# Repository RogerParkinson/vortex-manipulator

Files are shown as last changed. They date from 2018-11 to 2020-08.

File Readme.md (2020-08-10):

Vortex Manipulator
=

Mostly inspired by the wrist device worn by Captain Jack Harkness in _Dr Who_ and _Torchwood_, hence the name. However the design wandered somewhat from that initial idea so the look is a bit different. This is the idea I started with:

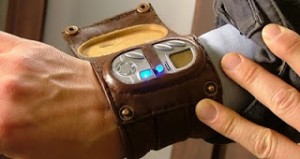
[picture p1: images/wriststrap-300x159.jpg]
VM


Mine is a little different, I needed more space to do what I want, so it is a bit fatter and it doesn't actually manipulate a time vortex (whatever that is). Instead it has the following functions:

 * Touch screen interface
 * Clock with optional beep and LED flash once a second, plus a function to set the time. It doesn't adjust automatically for daylight savings etc, but there is a UI to set the time manually.
 * Compass
 * Graphics demo
 * Dalek detector
 * Picture gallery (displays pictures from the SD card)
 * Heart rate monitor, including display graph and data log to SD card.
 * Sleep (power save) function, wakes up when the power button is pressed.
 * Notifications board. Messages from a Bluetooth device (eg a phone) display here.

Watch the video (https://youtu.be/WImzifKEVy0)

[Lots more details here](https://github.com/RogerParkinson/vortex-manipulator)

Hardware consists of a Teensy 3.2 mounted on a custom board [the Main Board](eagle/MainBoard/Readme.md) which contains circuitry for charging the attached LiPo battery when the USB port is connected, and an LSM303 to provide compass and accelerometer functions.

A second [ILI9341 custom connector board](eagle/ILI9341-Touch-connector/Readme.md) connects to an ILI9341 touch screen. This board has a touch controller and a connector strip that matches the strip on the side of the main board.

There are some configuration settings stored on the SD card (file is hconfig.txt) which consists of the time zone, low pulse and high pulse rates. The pulse rates are used by the HRM to sound alarms if the pulse is outside that range. The time zone is used for the clock (except it isn't actually used now). The other files on the SD card are bmp files used for the picture gallery. These must be 240x320 images. All of these files are in the SDBackup directory.

Perhaps more importantly it is a development _platform_. There is plenty of spare capacity in the Teensy and there is still plenty of room in the assembly to add more stuff. The Main Board has connectors to unused pins on the Teensy as well. An example of adding more stuff is the heart rate monitor. I got hold of a better one which uses an I2C interface and, hardware-wise, it was simple to add the extra connections to the SDA and SCL for it, then a bit more programming and the job was done.

The assembly is a mix of leather and a 3D printed frame.

Parts
-

 * [Teensy 3.2](https://www.pjrc.com/store/teensy32.html) microprocessor board
 * [LSM303](http://nz.element14.com/stmicroelectronics/lsm303dlhc/sensor-3-ch-accel-mag-mod-14lga/dp/2068595) Compass/accelerometer IC *
 * [SD Card Reader](https://www.aliexpress.com/item/Free-Shipping-5PCS-67840-8001-Conn-SD-Card-HDR-9-POS-Solder-RA-SMD-Embossed-T/32651979617.html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,searchweb201602_3_10152_10065_10151_10068_436_10136_10157_10137_10060_10138_10155_10062_10156_10154_10056_10055_10054_10059_100032_100033_100031_10099_10103_10102_10096_10147_10052_10053_10050_10107_10142_10051_10084_10083_10080_10082_10081_10110_10175_10111_10112_10113_10114_10181_10037_10183_10182_10185_10033_10032_10078_10079_10077_10073_10070_10123,searchweb201603_2,ppcSwitch_4&btsid=7b9c1a86-e8c1-4082-b529-14cabbf02189&algo_expid=712bfc6c-3058-4115-9f9d-6d221787d2ec-1&algo_pvid=712bfc6c-3058-4115-9f9d-6d221787d2ec) *
 * [Lipo Battery 3.7v](https://www.aliexpress.com/item/3-7V-1000mah-753050-Lithium-Polymer-LiPo-Rechargeable-Battery-For-Mp3-MP4-MP5-DVD-PAD-mobile/32293277274.html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,searchweb201602_3_10152_10065_10151_10068_436_10136_10157_10137_10060_10138_10155_10062_10156_10154_10056_10055_10054_10059_100032_100033_100031_10099_10103_10102_10096_10147_10052_10053_10050_10107_10142_10051_10084_10083_10080_10082_10081_10110_10175_10111_10112_10113_10114_10181_10037_10183_10182_10185_10032_10078_10079_10077_10073_10070_10123,searchweb201603_2,ppcSwitch_4&btsid=7691371f-396d-424d-b6fc-32f0ece90527&algo_expid=46b76ba9-9c3b-4e16-846a-75c4c1e89c21-4&algo_pvid=46b76ba9-9c3b-4e16-846a-75c4c1e89c21)
 * [2.4" 240x320 SPI Serial TFT Color LCD Display Module+ILI9341 Touch Panel Screen](https://www.aliexpress.com/item/2-8-2-8-Inch-240x320-SPI-Serial-TFT-Color-LCD-Display-Module-Touch-Panel-Screen/32681743271.html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) Make sure you get a *touch* screen, there are screens in the same format/packing that just display with no touch.
 * [XPT2046 Touch Controller](https://www.aliexpress.com/item/Free-shipping-20pcs-lot-XPT2046-2046-TSSOP16-new-original/32639677099.html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) *
 * [MCP73811](https://www.aliexpress.com/item/100-new-origina-MCP73811T-420I-OT-battery-management-chip-73811-MCP73811-Free-shipping-best-match/32713220952.html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,searchweb201602_3_10065_10068_10547_319_317_10548_10696_10084_453_10924_10083_454_10925_10926_10618_10920_10921_10307_10922_537_536_5733313_5733211_10059_10884_5733113_10887_100031_321_5733413_322_10103_5733612_5733513,searchweb201603_2,ppcSwitch_0&algo_expid=36e5927f-8c98-4996-90c5-7ffab6aace2d-0&algo_pvid=36e5927f-8c98-4996-90c5-7ffab6aace2d) battery management chip *
 * [LP298X](http://www.datasheetcafe.com/lp298xs-datasheet-low-dropout-regulator/) voltage regulator *
 * [Speaker 8 ohm](https://www.aliexpress.com/item/Manufacturers-direct-sales-round-8-European-1W-speaker-1w8-European-speakers-8-European-1W-speaker-20mm/32777445698.html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)
 * 2 LEDs (blue and green, or whatever colour you prefer)
 * 32.768Khz Crystal [soldered to the under side of the Teensy](https://www.pjrc.com/teensy/td_libs_Time.html) and a Coin Cell battery (CR2032) and holder.
 * [Switch](https://www.aliexpress.com/item/MINI-micro-Slide-Switch-On-OFF-2-Position-1P2T-SPDT-Miniature-Horizontal-Slide-Switch-SMD-7/32655484942.html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,searchweb201602_3_10152_10065_10151_10068_436_10136_10157_10137_10060_10138_10155_10062_10156_10154_10056_10055_10054_10059_100032_100033_100031_10099_10103_10102_10096_10147_10052_10053_10050_10107_10142_10051_10084_10083_10080_10082_10081_10110_10175_10111_10112_10113_10114_10181_10037_10183_10182_10185_10032_10078_10079_10077_10073_10070_10123,searchweb201603_2,ppcSwitch_4&btsid=4943b00a-2810-4553-922c-abebd41b5fcd&algo_expid=9ef925ce-c813-4853-b9b8-157b1cc2ff52-0&algo_pvid=9ef925ce-c813-4853-b9b8-157b1cc2ff52) *
 * [Button](https://www.aliexpress.com/item/Promotion-Amico-100-Pcs-6x6x4-5mm-Panel-PCB-Momentary-Tactile-Tact-Push-Button-Switch-4-Pin/32563399489.html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)
 * Various caps and resistors (see circuit diagrams for the boards)
 * [Heart Rate Monitor](https://www.aliexpress.com/item/Low-Power-MAX30102-Heart-Rate-Oxygen-Pulse-Breakout-for-Arduino-Replace-MAx30100/32892216359.html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) MAX30102 based breakout board.
 
Those marked with * are all surface mounted (SMD) parts.
 
Making the Icons
-

I developed an interesting technique for generating the icons for this project and I put it in its own [project](https://github.com/RogerParkinson/MakeIcons).

The SD card
-

The project uses an SD Card and you'll find a copy of mine in the SDBackup directory. It includes some bmp files which are images displayed by the gallery app, a configuration file calle hconfig.txt and a log file called datalog.txt.

The configuration file is one line: 12,120,150,
the 12 was once a timezone but I no longer use that. 120 and 150 are heart rate limits. The display turns green when you pass 120 and red when you pass 150. For me green means I'm in a good exercise zone, but your numbers may be different.

You can add your own bmp files. As long as they are 240x320 BMP format they will display in the gallery. When I export mine from Gimp I use these settings:

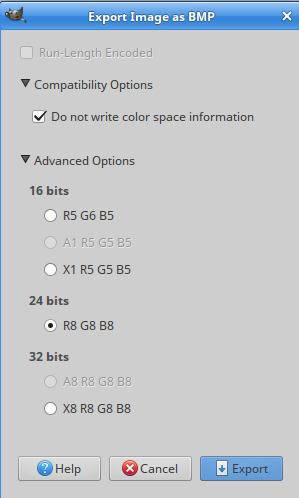
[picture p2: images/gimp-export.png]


Finally the datalog.txt file is a log of heart rates. The first column is a timestamp, then the beats per minute and finally the last interval between beats. It logs this every 10 minutes, the time is set in the setup() method in VortexManipulator.cpp:

```
intervals.create(10*60*1000L,new HRLogAction()); // 10 minutes
```

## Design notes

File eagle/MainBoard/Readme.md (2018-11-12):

Main board for the Vortex Manipulator
==

Main components:

 * Teensy 3.2 board. This holds the processor and the USB connector. It also has an on board clock powered by the small battery.
 * MicroSD. This holds configuration files and images. Heart rate logs go here.
 * LSM303 which provides a compass and an accelerometer.
 * LIPO charger circuit which charges the LIPO battery when the USB is connected.
 * Through hole connectors for the ILI9841 touch screen and various other connectors.
 
In addition to the ILI9341 connector strip on the main board there is a second strip just above it which has the following:

 * GND
 * Wake pulling this low (by the pushbutton) wakes us from shutdown mode.
 * Tone connects to the speaker.
 * LED1 connects to one of the LEDs.
 * LED2 connects to one of the LEDs.
 * Pulse no longer used.
 * Power no longer used.
 * Rx not yet used but connects to the Rx of the Teensy.
 * Tx not yet used but connects to the Tx of the Teensy.
 
A third strip just in front of the Teensy has some connectors that expose the under side connections of the Teensy for future expansion. These are:

 * A13
 * 33
 * 32
 * 31
 * 30
 * 29
 * A12

The [MAX30102 heart rate monitor](https://www.aliexpress.com/item/Low-Power-MAX30102-Heart-Rate-Oxygen-Pulse-Breakout-for-Arduino-Replace-MAx30100/32892216359.html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) is connected directly to the Teensy SDA and SCL pins, plus 3.3v power and GND.

Finally the Teensy on-board clock needs a backup coin cell battery connected to the battery and GND connectors on the Teensy.
 


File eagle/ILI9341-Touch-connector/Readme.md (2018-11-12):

ILI9341 connector for 14 pads + 4 pads for touch, broken out to 14 connector pins using a touch controller.

It is a clone of the PCB for [this screen](https://www.aliexpress.com/item/J34-F85-Free-Shipping-240x320-2-8-SPI-TFT-LCD-Touch-Panel-Serial-Port-Module-with/32599693865.html)
but without the SD card and the PCB is much smaller making it useful when you have very little room to mount it. The screen itself is available separately [here](https://www.aliexpress.com/item/J34-Free-Shipping-240x320-2-8-SPI-Serial-ILI9341-TFT-Color-LCD-Screen-Display-with-Touch/32435870215.html)

To build this you need a couple of resistors and ceramic capacitors as well as an [RT9169](https://www.aliexpress.com/item/Free-shipping-10pcs-lot-RT9169-30GV-RT9169-BK-SOT-23-new-original/32510597351.html)
and a [XPT2046 touch controller](https://www.aliexpress.com/item/Free-shipping-20pcs-lot-XPT2046-2046-TSSOP16-new-original/32639677099.html).

Aliexpress links come and go so if the links don't work then you can search for RT9169, and also for an ILI9341 screen. You want the screen _without_ the PCB because the already mounted on a PCB are too big (though they are easier to solder). Also make sure you order one with a touch capability. There are lots around that just display but are not touch screens. You also need the XPT2046 touch controller.

I used solder paste etc for the smd parts but I hand soldered the screen. It is fiddly work but I don't think it is a good idea to put the screen through an oven or hot plate.

Be careful when soldering the screen to the board. Those connections are very fine and, when soldered, rather fragile. Make sure you stick the board and screen together somehow, such as double sided tape, to prevent strain on the connection. It is important to get the screen connection around the right way. Check carefully before you solder.

For details on connecting the resulting board to your processor see [PJRC's instructions](https://www.pjrc.com/store/display_ili9341_touch.html).



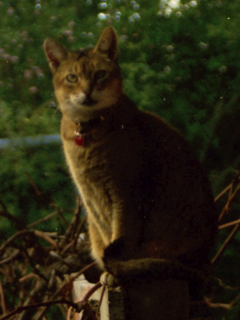
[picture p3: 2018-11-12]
SDBackup/kimi.bmp

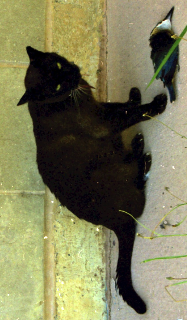
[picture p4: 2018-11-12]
SDBackup/sura.bmp

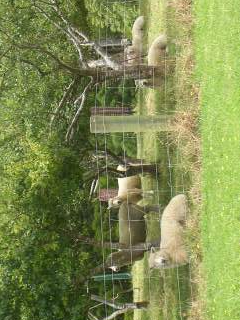
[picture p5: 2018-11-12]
SDBackup/sheep.bmp

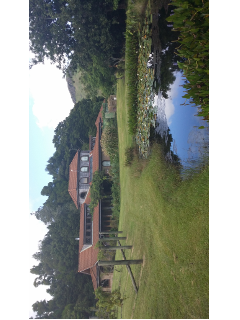
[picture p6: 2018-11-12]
SDBackup/house.bmp

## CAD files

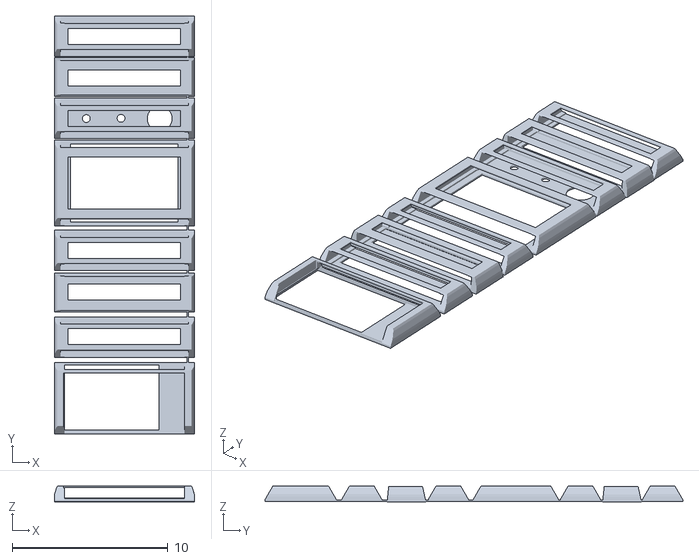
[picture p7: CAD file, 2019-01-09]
3DModel.stl
9.01 x 26.8 x 1.03

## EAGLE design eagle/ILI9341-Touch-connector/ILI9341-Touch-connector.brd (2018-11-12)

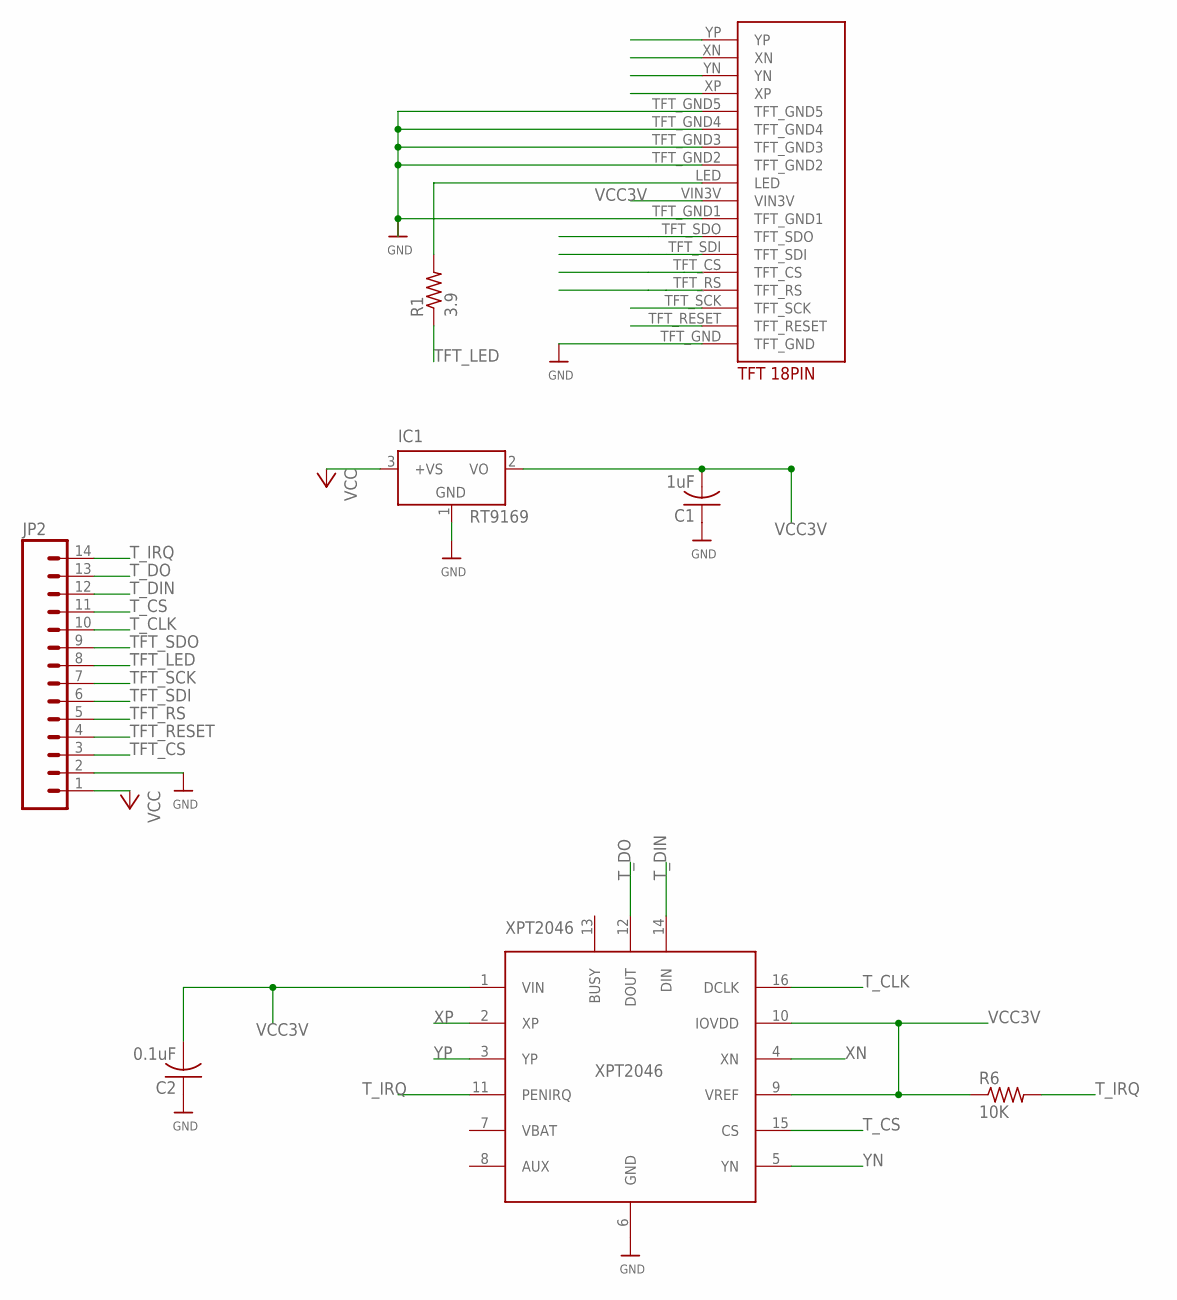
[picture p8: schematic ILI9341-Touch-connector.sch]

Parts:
C1: 1uF; C0805K
C2: 0.1uF; C0805K
IC1: RT9169; SOT23
JP2: M14; 1X14
R1: 3.9; R0805
R6: 10K; R0805
U$4: TFT_18PIN
XPT2046: XPT2046; TSSOP16-EXPOSED_PAD_MINIMAL

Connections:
GND: C1.1, C2.1, IC1.1 (GND), JP2.2, U$4.TFT_GND, U$4.TFT_GND1, U$4.TFT_GND2, U$4.TFT_GND3, U$4.TFT_GND4, U$4.TFT_GND5, XPT2046.6 (GND)
unnamed: R1.2, U$4.LED
TFT_CS: JP2.3, U$4.TFT_CS
TFT_LED: JP2.8, R1.1
TFT_RESET: JP2.4, U$4.TFT_RESET
TFT_RS: JP2.5, U$4.TFT_RS
TFT_SCK: JP2.7, U$4.TFT_SCK
TFT_SDI: JP2.6, U$4.TFT_SDI
TFT_SDO: JP2.9, U$4.TFT_SDO
T_CLK: JP2.10, XPT2046.16 (DCLK)
T_CS: JP2.11, XPT2046.15 (CS)
T_DIN: JP2.12, XPT2046.14 (DIN)
T_DO: JP2.13, XPT2046.12 (DOUT)
T_IRQ: JP2.14, R6.2, XPT2046.11 (PENIRQ)
VCC: IC1.3 (+VS), JP2.1
VCC3V: C1.2, C2.2, IC1.2 (VO), R6.1, U$4.VIN3V, XPT2046.1 (VIN), XPT2046.9 (VREF), XPT2046.10 (IOVDD)
XN: U$4.XN, XPT2046.4 (XN)
XP: U$4.XP, XPT2046.2 (XP)
YN: U$4.YN, XPT2046.5 (YN)
YP: U$4.YP, XPT2046.3 (YP)

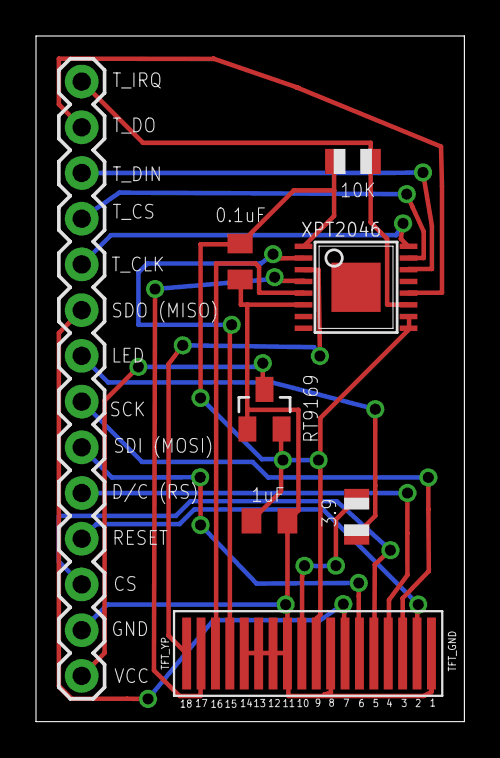
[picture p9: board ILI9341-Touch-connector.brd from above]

Board: 2 copper layers, 23.8 x 38.1 mm, 8 parts (0 on the bottom side), 20 nets.

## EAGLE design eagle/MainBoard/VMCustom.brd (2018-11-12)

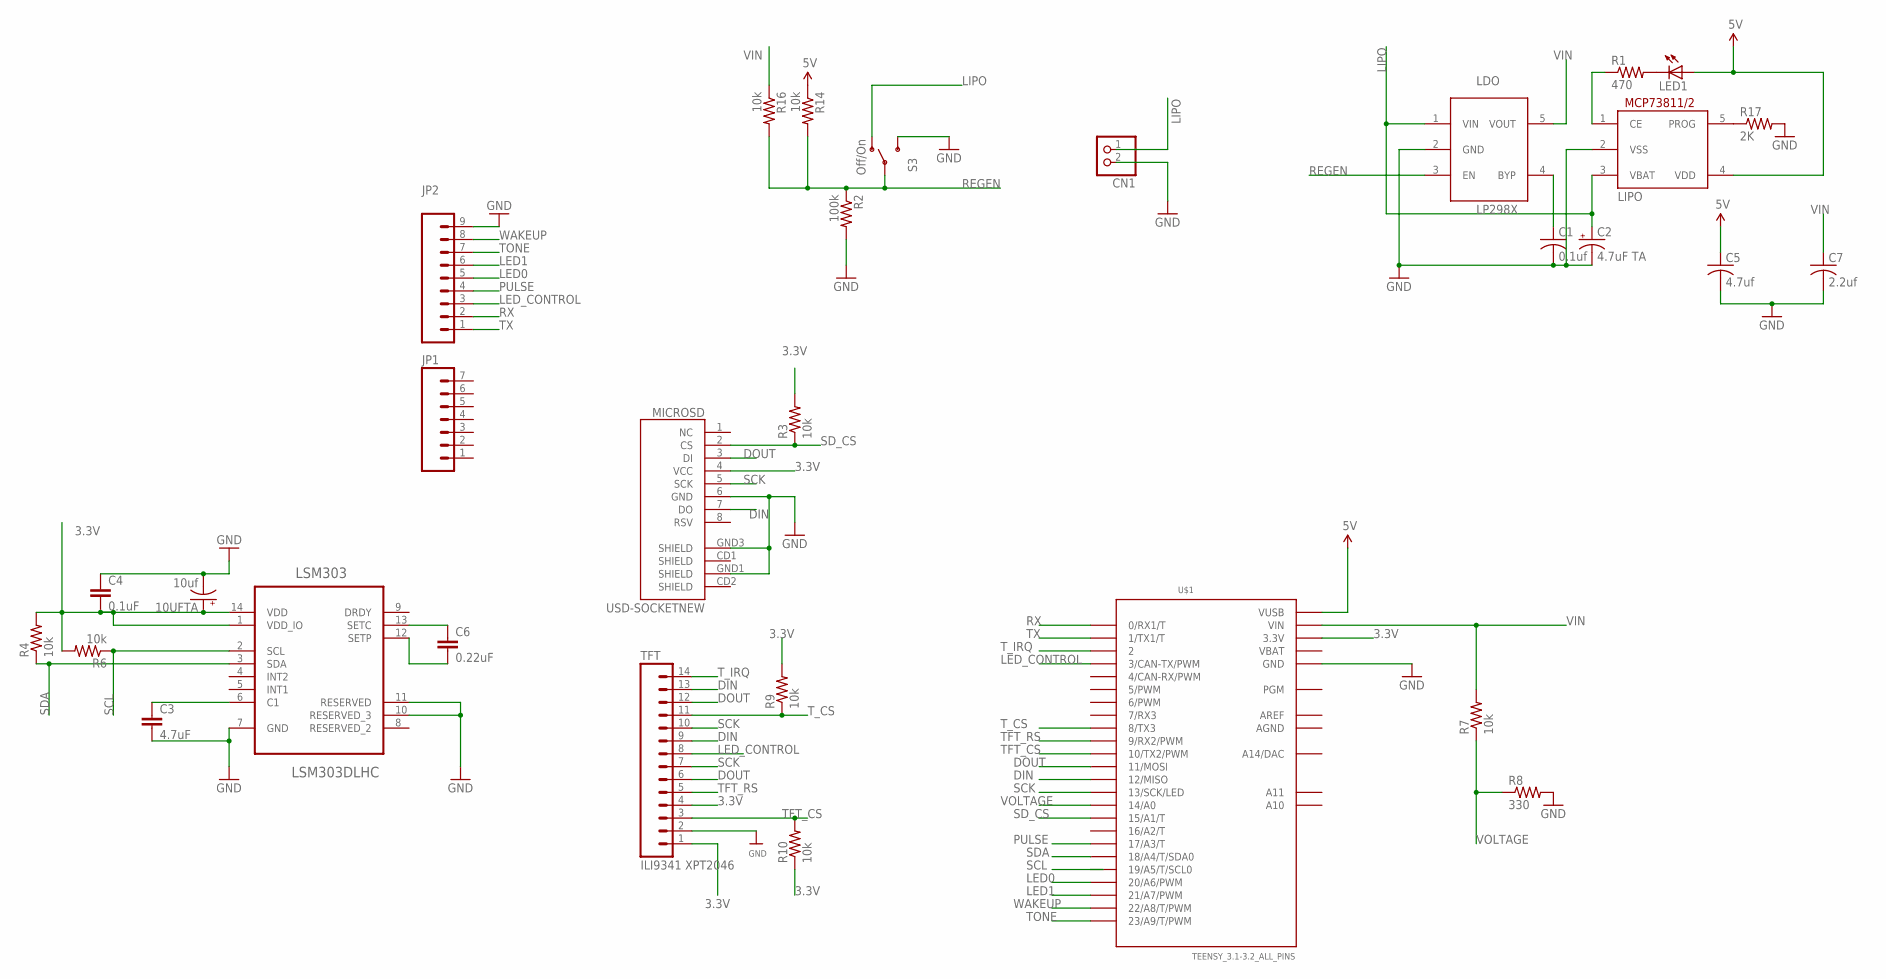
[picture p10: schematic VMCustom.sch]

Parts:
10UFTA: 10uf; EIA6032
C1: 0.1uf; C0805K
C2: 4.7uF TA; EIA3216
C3: 4.7uF; 0805
C4: 0.1uF; 0805
C5: 4.7uf; C0805K
C6: 0.22uF; 0805
C7: 2.2uf; C0805K
CN1: JST_2PIN-THM; JST-PH-2-THM
JP1: M07; 1X07
JP2: M09NO_SILK; 1X09_NO_SILK
LDO: LP298XS; SOT23-5L
LED1: LEDCHIPLED_0805; CHIPLED_0805
LIPO: MCP73811/2; SOT23-5L
LSM303: LSM303DLHC; LGA14R80P1X6
MICROSD: USD-SOCKETNEW; MICRO-SD-SOCKET-PP
R1: 470; M0805
R2: 100k; R0805
R3, R4, R6, R7, R9, R10: 10k; 0805
R8: 330; 0805
R14, R16: 10k; R0805
R17: 2K; M0805
S3: Off/On; SWITCH-SPST-SMD-A
TFT: ILI9341 XPT2046; 1X14
U$1: TEENSY_3.1-3.2_ALL_PINS; TEENSY_3.0-3.2&LC_ALL_PINS

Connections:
3.3V: 10UFTA.P$1 (+), C4.2, LSM303.1 (VDD_IO), LSM303.14 (VDD), MICROSD.4 (VCC), R3.2, R4.2, R6.2, R9.2, R10.1, TFT.1, TFT.4, U$1.3.3V, U$1.3.3V1 (3.3V)
5V: C5.1, LED1.A, LIPO.4 (VDD), R14.1, U$1.VUSB
AGND: U$1.AGND
AREF: U$1.AREF
DIN: MICROSD.7 (DO), TFT.9, TFT.13, U$1.12 (12/MISO)
DOUT: MICROSD.3 (DI), TFT.6, TFT.12, U$1.11 (11/MOSI)
GND: 10UFTA.P$2 (-), C1.2, C2.C (-), C3.2, C4.1, C5.2, C7.2, CN1.2 (1), JP2.9, LDO.2 (GND), LIPO.2 (VSS), LSM303.7 (GND), LSM303.10 (RESERVED_3), LSM303.11 (RESERVED), MICROSD.6 (GND), MICROSD.GND1 (SHIELD), MICROSD.GND3 (SHIELD), R2.2, R8.2, R17.2, S3.3 (S), TFT.2, U$1.GND, U$1.GND1 (GND)
LED0: JP2.5, U$1.20/A6 (20/A6/PWM)
LED1: JP2.6, U$1.21/A7 (21/A7/PWM)
LED_CONTROL: JP2.3, TFT.8, U$1.3 (3/CAN-TX/PWM)
LIPO: C2.A (+), CN1.1 (2), LDO.1 (VIN), LIPO.3 (VBAT), S3.1 (O)
unnamed: LIPO.1 (CE), R1.1
unnamed: C3.1, LSM303.6 (C1)
unnamed: LED1.C, R1.2
unnamed: C1.1, LDO.4 (BYP)
unnamed: C6.1, LSM303.13 (SETC)
unnamed: C6.2, LSM303.12 (SETP)
unnamed: LIPO.5 (PROG), R17.1
PULSE: JP2.4, U$1.17/A3 (17/A3/T)
REGEN: LDO.3 (EN), R2.1, R14.2, R16.2, S3.2
RX: JP2.2, U$1.0 (0/RX1/T)
SCK: MICROSD.5 (SCK), TFT.7, TFT.10, U$1.13 (13/SCK/LED)
SCL: LSM303.2 (SCL), R6.1, U$1.19/A5 (19/A5/T/SCL0)
SDA: LSM303.3 (SDA), R4.1, U$1.18/A4 (18/A4/T/SDA0)
SD_CS: MICROSD.2 (CS), R3.1, U$1.15/A1 (15/A1/T)
TFT_CS: R10.2, TFT.3, U$1.10 (10/TX2/PWM)
TFT_RS: TFT.5, U$1.9 (9/RX2/PWM)
TONE: JP2.7, U$1.23/A9 (23/A9/T/PWM)
TX: JP2.1, U$1.1 (1/TX1/T)
T_CS: R9.1, TFT.11, U$1.8 (8/TX3)
T_IRQ: TFT.14, U$1.2
VBAT: U$1.VBAT
VIN: C7.1, LDO.5 (VOUT), R7.2, R16.1, U$1.VIN
VOLTAGE: R7.1, R8.1, U$1.14/A0
WAKEUP: JP2.8, U$1.22/A8 (22/A8/T/PWM)

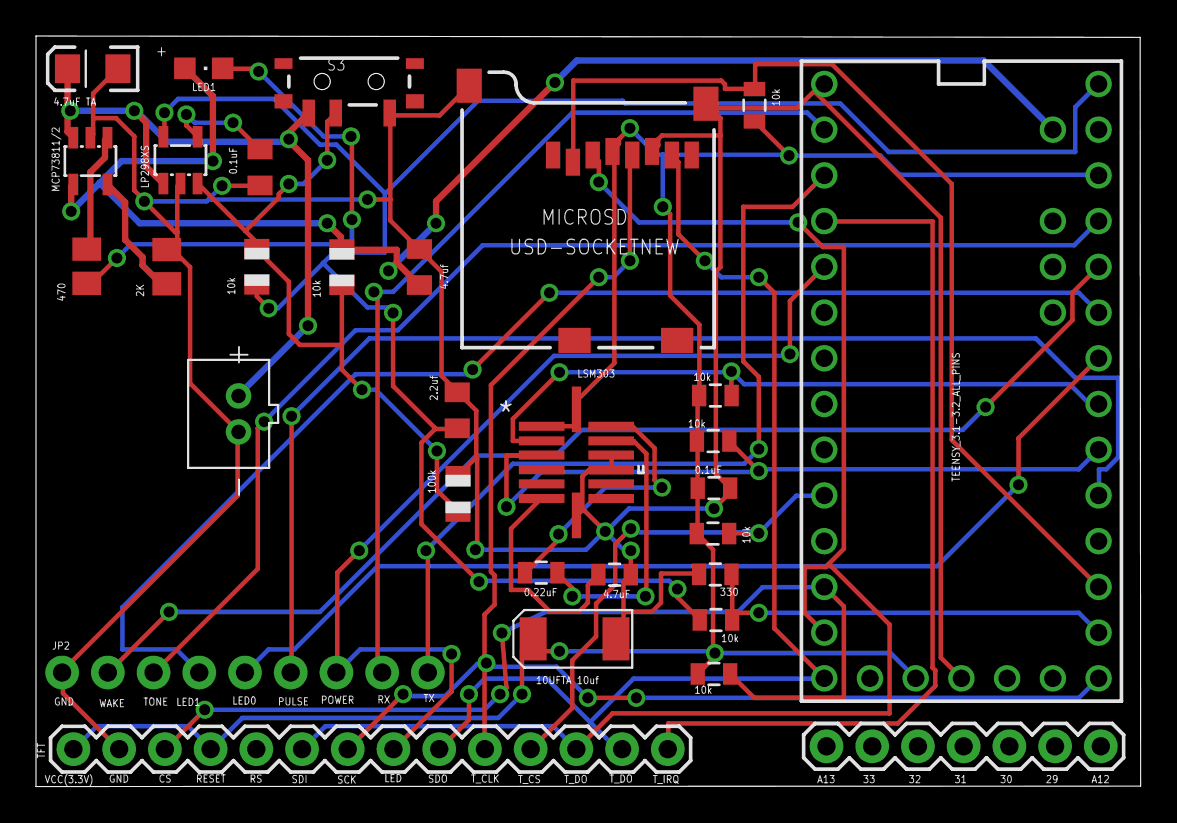
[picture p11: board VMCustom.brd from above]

Board: 2 copper layers, 61.4 x 41.7 mm, 31 parts (0 on the bottom side), 32 nets.

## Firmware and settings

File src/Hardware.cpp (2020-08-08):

/*
 * Hardware.cpp
 *
 * Provides a simple access point for all the hardware connected
 * If we connect more hardware to the device we need to add access methods here.
 *
 *  Created on: 22/05/2013
 *      Author: roger
 */

#include "Hardware.h"


ILI9341_t3 Graphics(TFT_CS, TFT_DC);
MAX30105 particleSensor;
TimeChangeRule nzSTD = {"NZST", First, Sun, Apr, 3, 720};   // UTC + 12 hours
TimeChangeRule nzDST = {"NZDT", Last, Sun, Sep, 2, 780};    // UTC + 13 hours
Timezone nz(nzDST, nzSTD);


// For better pressure precision, we need to know the resistance
// between X+ and X- Use any multimeter to read it
// For the one we're using, its 371 ohms across the X plate
// measured again on 13/08/14 it floats around a bit but say 85
XPT2046_Touchscreen Touchscreen = XPT2046_Touchscreen(TS_CS,TIRQ_PIN);


Hardware_::Hardware_() {
	loggerHardware = loggerFactory.getLogger("Hardware");
	m_lsm303 = LSM303();
	// Calibration values. Use the Calibrate example program to get the values for
	// your compass.
	m_lsm303.m_min.x = -880;
	m_lsm303.m_min.y = -691;
	m_lsm303.m_min.z = -958;
	m_lsm303.m_max.x = +262;
	m_lsm303.m_max.y = +365;
	m_lsm303.m_max.z = -27;

	m_lsm303.m_min.x = -495;
	m_lsm303.m_min.y = -463;
	m_lsm303.m_min.z = +393;
	m_lsm303.m_max.x = +495;
	m_lsm303.m_max.y = +279;
	m_lsm303.m_max.z = +627;
	m_compassCorrection = 550;

	//CircularBuffer cb = CircularBuffer(10);

}
/*
 * Put us into hibernate mode. Need to press the restart button to come out of this.
 */
void Hardware_::shutdown() {
	Graphics.setRotation(3);
	Graphics.fillScreen(BLACK);
	Graphics.setTextSize(2);
	Graphics.setCursor(80,Graphics.height()/2);
	Graphics.print(PSTR("sleeping..."));
	delay(1000);
	Graphics.fillScreen(BLACK);
	heartRateInterrupt.reset();
	loggerHardware->debug("shutdown...");
	compass(false);
	Graphics.sleep(true);
	digitalWrite(LED_CONTROL_PIN, LOW);
	pinMode(22, INPUT_PULLUP);
	m_lowPower.DeepSleep(GPIO_WAKE, PIN_22);
	// We get here when we wake up
	digitalWrite(LED_CONTROL_PIN, HIGH);
	blink0();
	blink1();
	Graphics.sleep(false);
	Graphics.begin();
	Graphics.fillScreen(BLACK);
	Serial.begin(9600);
	loggerHardware->debug("starting up after shutdown...");
	setSyncProvider((getExternalTime)Teensy3Clock.get); // resync the clock when we wake up
	//Teensy3Clock.compensate(0);
	startup.run();
}

/*
 * Put us into soft sleep mode.
 */
void Hardware_::sleep() {

	loggerHardware->debug("sleep...");
	compass(false);
	Graphics.sleep(true);
	digitalWrite(LED_CONTROL_PIN, LOW); // this also turns off HR
	sleeping = true;
}

bool Hardware_::isSleeping() {
	return sleeping;
}

/*
 * Wake up from sleep.
 */
void Hardware_::wake() {

	digitalWrite(LED_CONTROL_PIN, HIGH);
	blink0();
	blink1();
	Graphics.sleep(false);
	Graphics.begin();
	loggerHardware->debug("waking after sleep...");
	setSyncProvider((getExternalTime)Teensy3Clock.get); // resync the clock when we wake up
	//Teensy3Clock.compensate(0);
	sleeping = false;
}

void Hardware_::init()
{
	pinMode(SD_CS, OUTPUT);
	pinMode(LED0_PIN, OUTPUT);
	pinMode(LED1_PIN, OUTPUT);
	pinMode(LED_CONTROL_PIN, OUTPUT);
	digitalWrite(LED_CONTROL_PIN, HIGH);
	Wire.begin();
	beginSD();
	loggerHardware->debug("starting LMS303");
	m_lsm303.init();
	m_lsm303.enableDefault();
	compass(false);
	loggerHardware->debug("LMS303 done");
	Graphics.begin();
	Graphics.fillScreen(BLACK);
	Graphics.setFont(getDefaultFont());
	Touchscreen.begin();
	m_lowPower = TEENSY3_LP();
	sleeping = false;
	loggerHardware->debug("tft done");

	// initialise bluetooth
//	bluetooth.begin(115200);  // The Bluetooth Mate defaults to 115200bps
	bluetooth.begin(9600);  // The CC2450 defaults to 9600bps
//	bluetooth.print("$");  // Print three times individually
//	bluetooth.print("$");
//	bluetooth.print("$");  // Enter command mode
//	delay(100);  // Short delay, wait for the Mate to send back CMD
//	bluetooth.println("U,9600,N");  // Temporarily Change the baudrate to 9600, no parity
//	// 115200 can be too fast at times for NewSoftSerial to relay the data reliably
//	bluetooth.begin(9600);  // Start bluetooth serial at 9600
//	bluetooth.print("-");  // Print three times individually
//	bluetooth.print("-");
//	bluetooth.print("-");  // Exit command mode

	if (!particleSensor.begin(Wire, I2C_SPEED_FAST)) {//Use default I2C port, 400kHz speed
		loggerHardware->error("MAX30105 was not found. Please check wiring/power. ");
	} else {
		loggerHardware->debug("MAX30105 detected");
		particleSensor.setup(); //Configure sensor with default settings
		particleSensor.setPulseAmplitudeRed(0x0A); //Turn Red LED to low to indicate sensor is running
		particleSensor.setPulseAmplitudeGreen(0); //Turn off Green LED
	}


}

void Hardware_::playTone(uint16_t frequency, uint32_t duration, uint32_t delay_after) {
	loggerHardware->debug("tone");
	tone(TONE_PIN, frequency,duration);
	delay(delay_after);
	noTone(TONE_PIN);
}
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

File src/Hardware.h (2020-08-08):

/*
 * Hardware.h
 *
 *  Created on: 22/05/2013
 *      Author: roger
 */

#ifndef HARDWARE_H_
#define HARDWARE_H_
#include <LSM303.h>
#include <ILI9341_t3.h>
#include <font_Arial.h> // from ILI9341_t3
#include <XPT2046_Touchscreen.h>
#include <SD.h>
#include <Wire.h>
#include <Time.h>
#include <LowPower_Teensy3.h>
#include "heartrate/HeartRateInterrupt.h"
#include <MAX30105.h>

#include <heartRate.h>
#include "ui/Startup.h"
#include <SoftwareSerial.h>
#include <Logger.h>
#include <Timezone.h>   // https://github.com/JChristensen/Timezone
#include <TimeLib.h>    // https://github.com/PaulStoffregen/Time

//#define HARDWARE_DEBUG
#define ICON_DEBUG
#define TS_CS 8
#define TIRQ_PIN  2
#define TFT_DC  9
#define TFT_CS 10
#define SD_CS 15
extern ILI9341_t3 Graphics;

// Assign human-readable names to some common 16-bit color values:
#define	BLACK   0x0000
#define	BLUE    0x001F
#define	RED     0xF800
#define	GREEN   0x07E0
#define CYAN    0x07FF
#define MAGENTA 0xF81F
#define YELLOW  0xFFE0
#define WHITE   0xFFFF

#define TS_MINX 150
#define TS_MINY 130
#define TS_MAXX 3800
#define TS_MAXY 4000

#define TONE_PIN 23
#define LED0_PIN 20
#define LED1_PIN 21
#define VOLTAGE 0 // actually A0. This is the battery voltage measure pin 14
#define PULSE_PIN 17 // pin 17 (A3)
#define LED_CONTROL_PIN 3 // controls the LED brightness & power to compass and HRM

#define HEADER_PIXEL(data,pixel) {\
pixel[0] = (((data[0] - 33) << 2) | ((data[1] - 33) >> 4)); \
pixel[1] = ((((data[1] - 33) & 0xF) << 4) | ((data[2] - 33) >> 2)); \
pixel[2] = ((((data[2] - 33) & 0x3) << 6) | ((data[3] - 33))); \
data += 4; \
}
#define bluetooth Serial1
#define DSTRING_SIZE 60

class Icon {
public:
	unsigned int size;
	const uint16_t *icon;
	bool reversed;
	Icon(const unsigned int s, const uint16_t data[]) {
		size = s;
		icon = data;
		reversed=false;
	};
	void reverse(bool r) {
		reversed = r;
	}
	virtual ~Icon() {
	};
	const void draw(const int x, const int y) {
		if (icon != NULL) {
			int count = 0;
			for (unsigned int j = 0; j < size; j++) {

				for (unsigned int i = 0; i < size; i++) {
					uint16_t pixel = icon[count++];
					if (reversed) {
						pixel = ~pixel;
					}
					Graphics.drawPixel(x + i, y + j, pixel);
				}
			}
		}
	}
};


class Hardware_ {
private:
	Logger *loggerHardware;
	LSM303 m_lsm303;
	char dstring[DSTRING_SIZE];
	bool m_sdOK=false;
	TEENSY3_LP m_lowPower;
	int m_compassCorrection;
	bool sleeping = false;

public:
	Hardware_();
	void init();
	void shutdown();
	void sleep();
	void wake();
	bool isSleeping();
	int compassHeading();
	void compass(bool start);
	void blink0() {
		digitalWrite(LED0_PIN, HIGH);
		delay(50);
		digitalWrite(LED0_PIN, LOW);
	}
	void blink1() {
		digitalWrite(LED1_PIN, HIGH);
		delay(50);
		digitalWrite(LED1_PIN, LOW);
	}
	LSM303::vector<int16_t> getAccelerometerValues();
	bool isSDOK() { return m_sdOK;};
	bool beginSD();
	const char *timeString(long adjustedDate);
	const char *timeString(int hour, int minute, int second);
	const char *dateString(long adjustedDate);
	void setCompassCorrection(const char *str);
	int getCompassCorrection();
	void progmemPrint(const char *str);
	void progmemPrintln(const char *str);
	void printDirectory(File dir, int numTabs);
	int readInt(File dataFile);
	float getBatteryVoltage();
	void playTone(uint16_t frequency, uint32_t duration = 0, uint32_t delay_after = 40);
	void siren();
	const ILI9341_t3_font_t &getDefaultFont() {
		return Arial_10;
	}
	void dumpSD(const char *message) {
		Serial.print(PSTR("dumpSD "));
		Serial.println(message);
		File root = SD.open("/");
		printDirectory(root, 0);
		root.close();
		Serial.print(PSTR("dumpSD done ("));
		Serial.print(message);
		Serial.println(")");
	}
	uint16_t read16(File f);
	uint32_t read32(File f);
	void bufferAccelerometer();
	const char *readBluetooth();
	virtual ~Hardware_();
};

extern Hardware_ Hardware;
extern XPT2046_Touchscreen Touchscreen;
extern ILI9341_t3 Graphics;
extern MAX30105 particleSensor;
extern Timezone nz;


#endif /* HARDWARE_H_ */

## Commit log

2018-11-12 added eagle files and readme
    [ILI9341-Touch-connector.brd, ILI9341-Touch-connector.sch, VMCustom.brd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]
2018-11-25 reworked interval classes to use millis and cycle
2018-11-26 turned off debug and added nonfunctional mars button to clock
2018-11-27 coded but not working
    [VortexManipulator.h]
2018-12-03 Integrating new logging mechanism finished
    [Configuration.h]
2019-01-09 added stl file, tidied readme file, set logger factory to false
    [3DModel.stl]
2019-05-12 commented out test switches
2020-08-02 notifications working, including filters
2020-12-05 flags back to production and updated to 1.54
    [Configuration.h]

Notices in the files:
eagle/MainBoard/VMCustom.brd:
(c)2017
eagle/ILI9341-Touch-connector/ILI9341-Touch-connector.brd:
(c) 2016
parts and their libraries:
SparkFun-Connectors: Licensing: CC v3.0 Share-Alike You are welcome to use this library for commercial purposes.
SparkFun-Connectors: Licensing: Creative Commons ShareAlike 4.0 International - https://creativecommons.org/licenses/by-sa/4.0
